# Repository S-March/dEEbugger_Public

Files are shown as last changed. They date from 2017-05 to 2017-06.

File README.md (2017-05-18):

# dEEbugger
[The dEEbugger is an ESP8266 based keychain swiss army knife for electronics](https://gfycat.com/OrneryPlushAbalone)

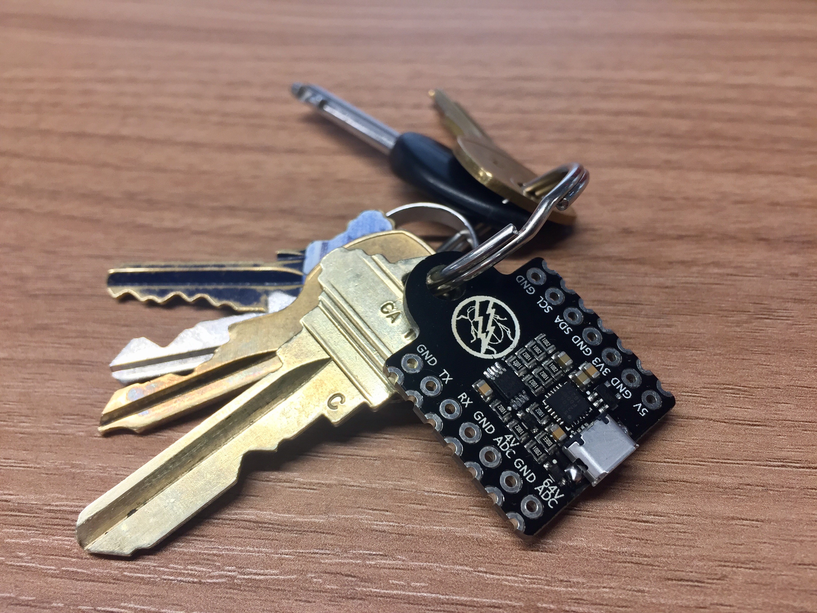
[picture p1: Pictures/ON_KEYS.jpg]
Keychain


The device was designed with breakouts for the two ADC channels, UART and I2C. It can run off of 5V or 3.3V or USB power. If USB is being used, the 5V and 3.3V pins can be used as outputs.

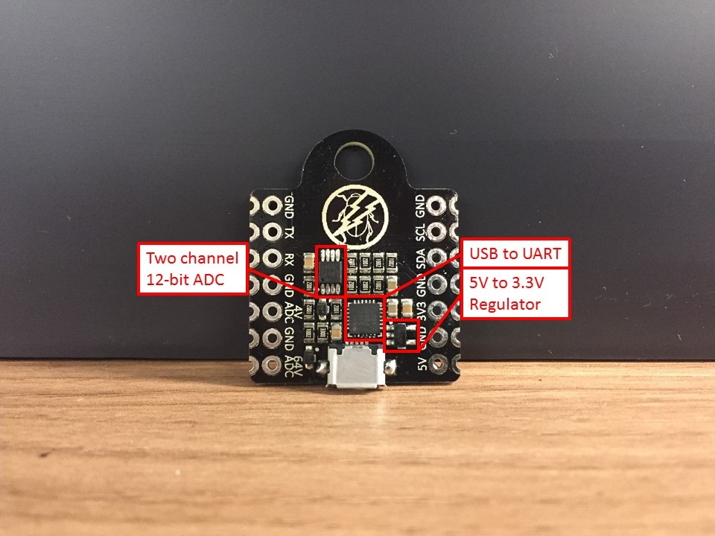
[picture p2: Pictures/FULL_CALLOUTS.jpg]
Callout Main


## Oscilloscope
To use the dEEbugger, plug in power and navigate to dEEbugger.local in you browser. If your devices does not support mDNS, you can just navigate to the dEEbugger IP address instead.

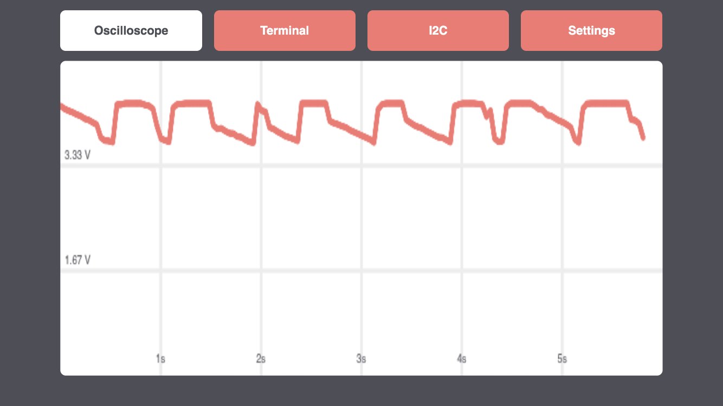
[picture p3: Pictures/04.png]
Oscilloscope Main

#### Two Channels (ADC and UART Stream)
Chose between multiple inputs for the channels. In the below picture the red is an ADC channel and the blue is a UART stream of numbers.

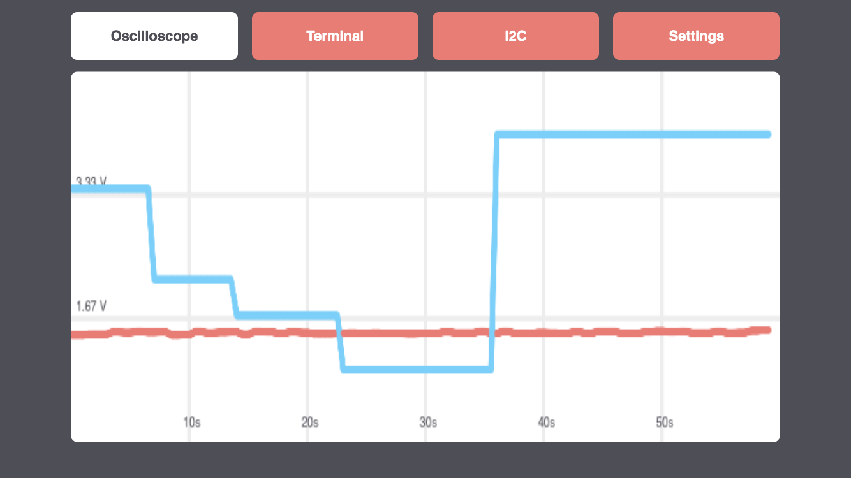
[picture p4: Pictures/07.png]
Two Channels

#### Peak Detection
The dEEbugger supports real time peak detection as well.

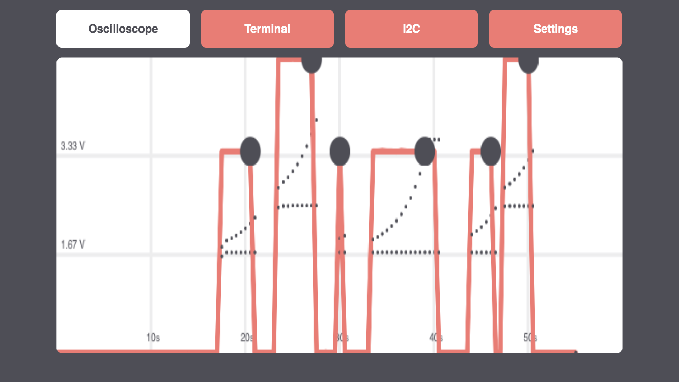
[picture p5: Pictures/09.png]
Peak Detection


## Serial Terminal
#### Local Echo
In additin to acting as an oscilloscope, the dEEbugger can act as a "wireless" serial terminal allowing you to send and receive data over the UART pins through the web application

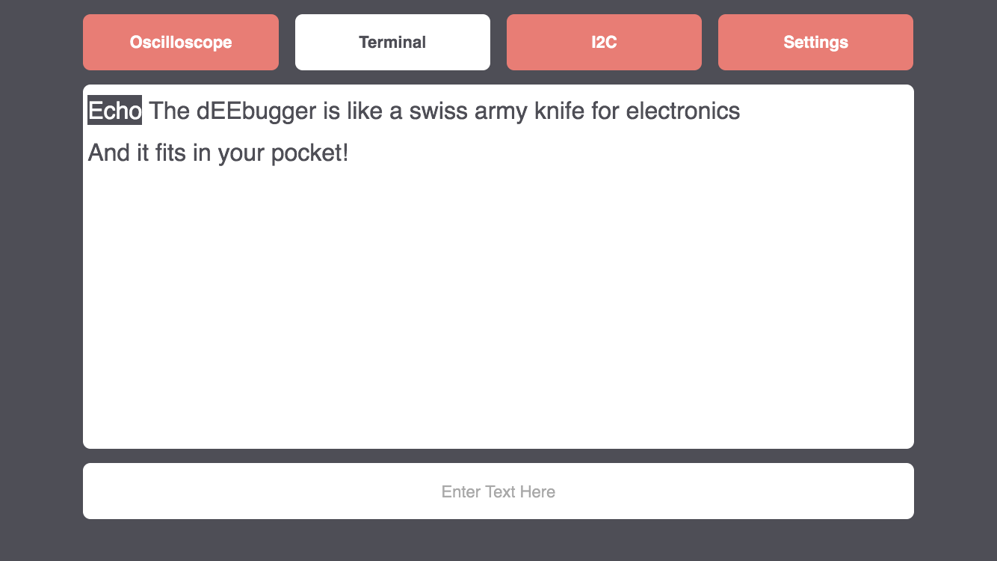
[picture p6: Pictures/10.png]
Local Echo

#### Terminal Options
Terminal settings: connect/disconnect button, baud rate selection, terminal clear button and enable/disable a local echo.

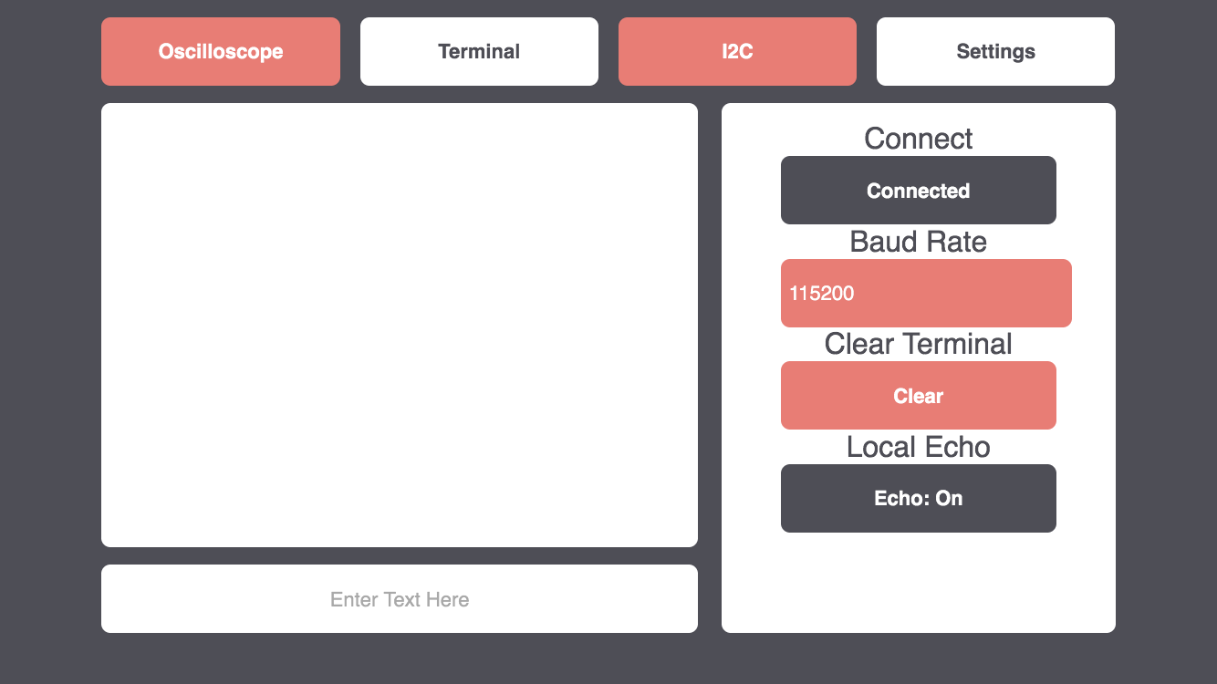
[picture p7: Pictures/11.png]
Terminal Options


## I2C Controller
#### Find Devices
When "Find Devices" button is pressed, a list of all I2C devices on the bus will be returned.

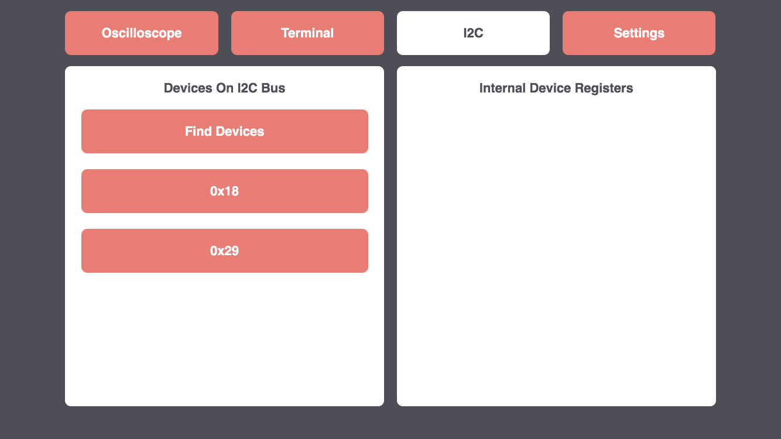
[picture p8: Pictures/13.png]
Find Devices

#### Read Device
When a device is selected, all readable registers will be returned with their current values.

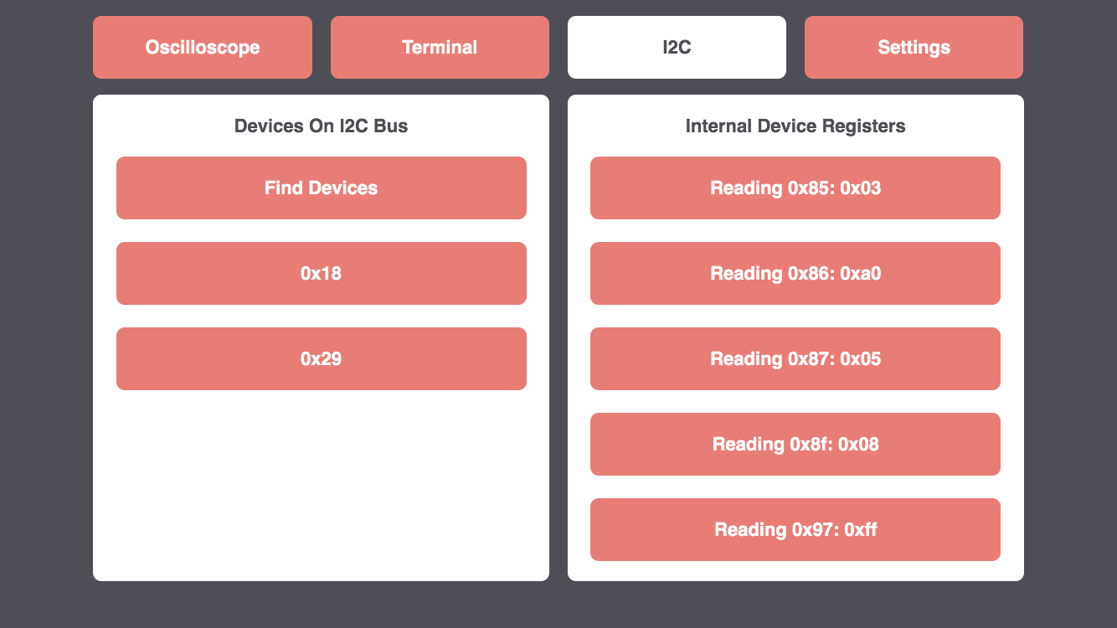
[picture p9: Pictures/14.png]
Read Device


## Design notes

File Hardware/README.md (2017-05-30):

## Fabrication
You can either send the release files to your board house of choice or you can [order PCBs directly from here](http://dirtypcbs.com/store/designer/details/Smarch/3586/deebugger-5-17-17-release-zip)
## Bill of materials
The dEEbugger_BOM file contains all the parts you will need to assemble a dEEbugger. The last column contains the distributor part number (e.g. copy and paste into Digikey) or use the link provided.
## Assembly
To assemble a dEEbugger, use the below image to place components.
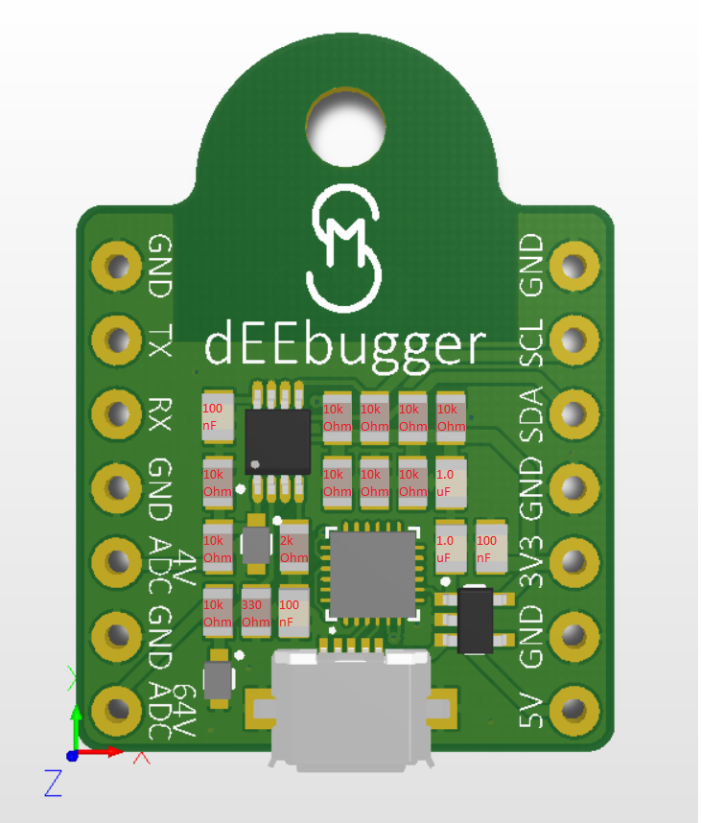
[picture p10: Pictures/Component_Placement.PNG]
Components


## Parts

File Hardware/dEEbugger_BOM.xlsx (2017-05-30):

Part Number | Quantity | Description | Comment | Supplier | Distributor | Distributor Part Number/Link
RC0805FR-0710KL | 10 | 10K 0.5W 1% 0805 | 10K | Yageo | Digikey | 311-10.0KCRCT-ND (https://www.digikey.com/products/en?keywords=311-10.0KCRCT-ND)
CL21B104MBCNNNC | 3 | CAP 100nF 10V ±20% 0805 (2012 Metric) Thickness 1mm SMD | 100nF | Samsung | Digikey | 1276-2450-1-ND (https://www.digikey.com/products/en?keywords=1276-2450-1-ND)
CL21B105KOFNNNG | 2 | CAP 1uF 10V ±20% 0805 (2012 Metric) Thickness 1.45mm SMD | 1uF | Samsung | Digikey | 1276-6471-1-ND (https://www.digikey.com/products/en?keywords=1276-6471-1-ND)
MM3Z3V3T1G | 2 | Zener Voltage Regulator, 300 mW, 2-Pin SOD-323, Pb-Free, Tape and Reel | MM3Z3V3T1G | On Semi | Digikey | MM3Z3V3T1GOSCT-ND (https://www.digikey.com/products/en?keywords=MM3Z3V3T1GOSCT-ND)
RC0805FR-072KL | 1 | 2K 0.125W 1% 0805 (2012 Metric) SMD | 2K | Yageo | Digikey | 311-2.00KCRCT-ND (https://www.digikey.com/products/en?keywords=311-2.00KCRCT-ND)
RC0805FR-07330RL | 1 | 330R 0.125W 1% 0805 (2012 Metric) SMD | 330R | Yageo | Digikey | 311-330CRCT-ND (https://www.digikey.com/products/en?keywords=311-330CRCT-ND)
AP2112K-3.3TRG1 | 1 | 3.3V LDO | AP2112K-3.3 | Diodes Inc | Digikey | AP2112K-3.3TRG1DICT-ND (https://www.digikey.com/products/en?keywords=AP2112K-3.3TRG1DICT-ND)
ESP-12F | 1 | ESP8266 Module | ESP8266 Module | Espressif | ALIEXPRESS | ALIEXPRESS (https://www.aliexpress.com/store/product/2015-New-version-1PCS-ESP-12F-ESP-12E-upgrade-ESP8266-remote-serial-Port-WIFI-wireless-module/1735233_32643052680.html)
MAX11645EUA+ | 1 | MAX11645 12 Bit Analog to Digital Converter 1, 2 Input 1 SAR 8-uMAX | MAX11645 | Maxim | Digikey | MAX11645EUA+-ND (https://www.digikey.com/products/en?keywords=MAX11645EUA%2B-ND)
CP2104-F03-GM | 1 | USB to UART bridge | USB to UART Bridge | Silicon Labs | Digikey | 336-2008-5-ND (https://www.digikey.com/products/en?keywords=336-2008-5-ND)
USB3100-30-A | 1 | Flipped USB Connector, Micro USB Type B, USB 2.0, Receptacle, 5 Positions, Surface Mount, Right Angle | USB3100-30-A Flipped USB | GCT | Newark | 07W3659 (http://www.newark.com/global-connector-technology/usb3100-30-a/micro-usb-2-0-type-b-receptacle/dp/07W3659)

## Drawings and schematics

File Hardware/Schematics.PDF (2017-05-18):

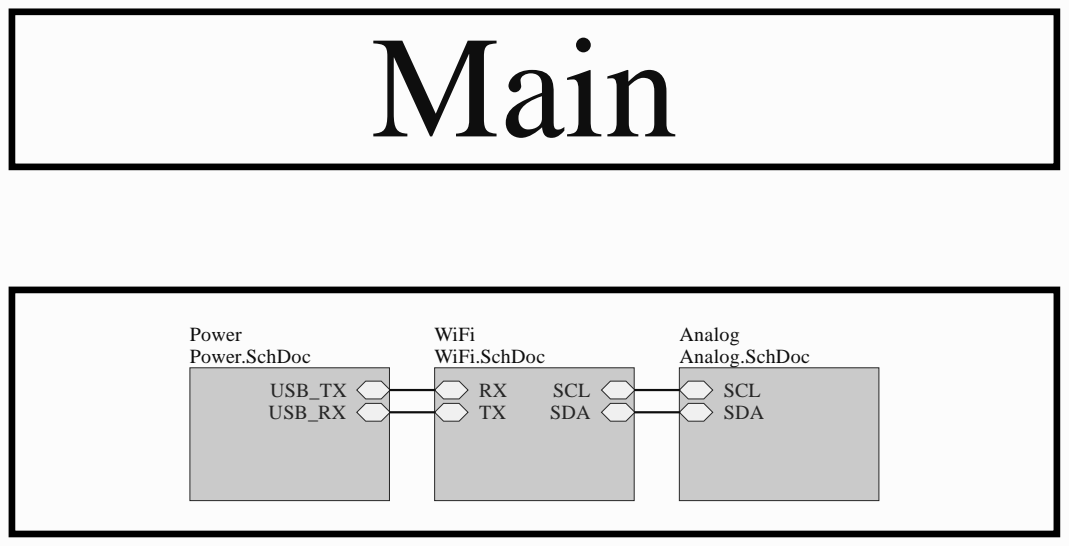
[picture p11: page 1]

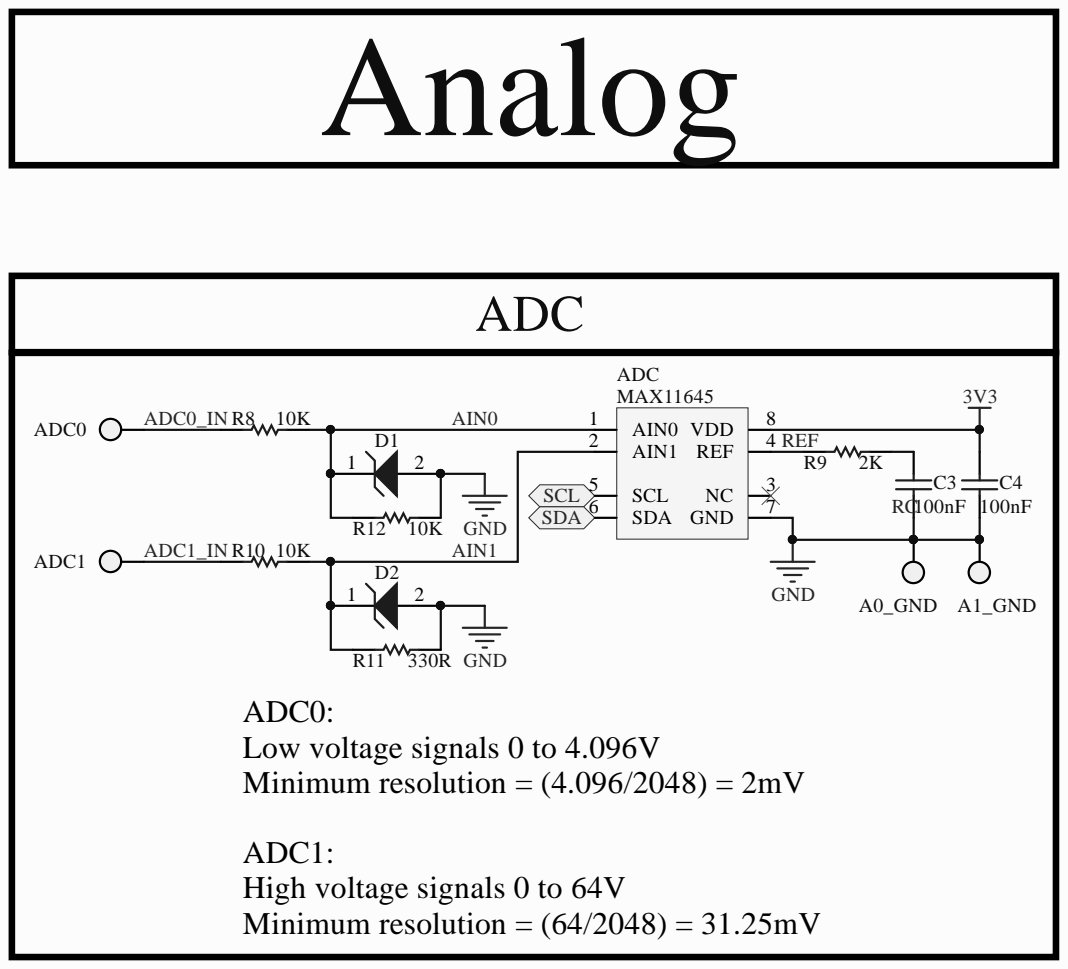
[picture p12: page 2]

ADC0:
Low voltage signals 0 to 4.096V
Minimum resolution = (4.096/2048) = 2mV

ADC1:
High voltage signals 0 to 64V
Minimum resolution = (64/2048) = 31.25mV

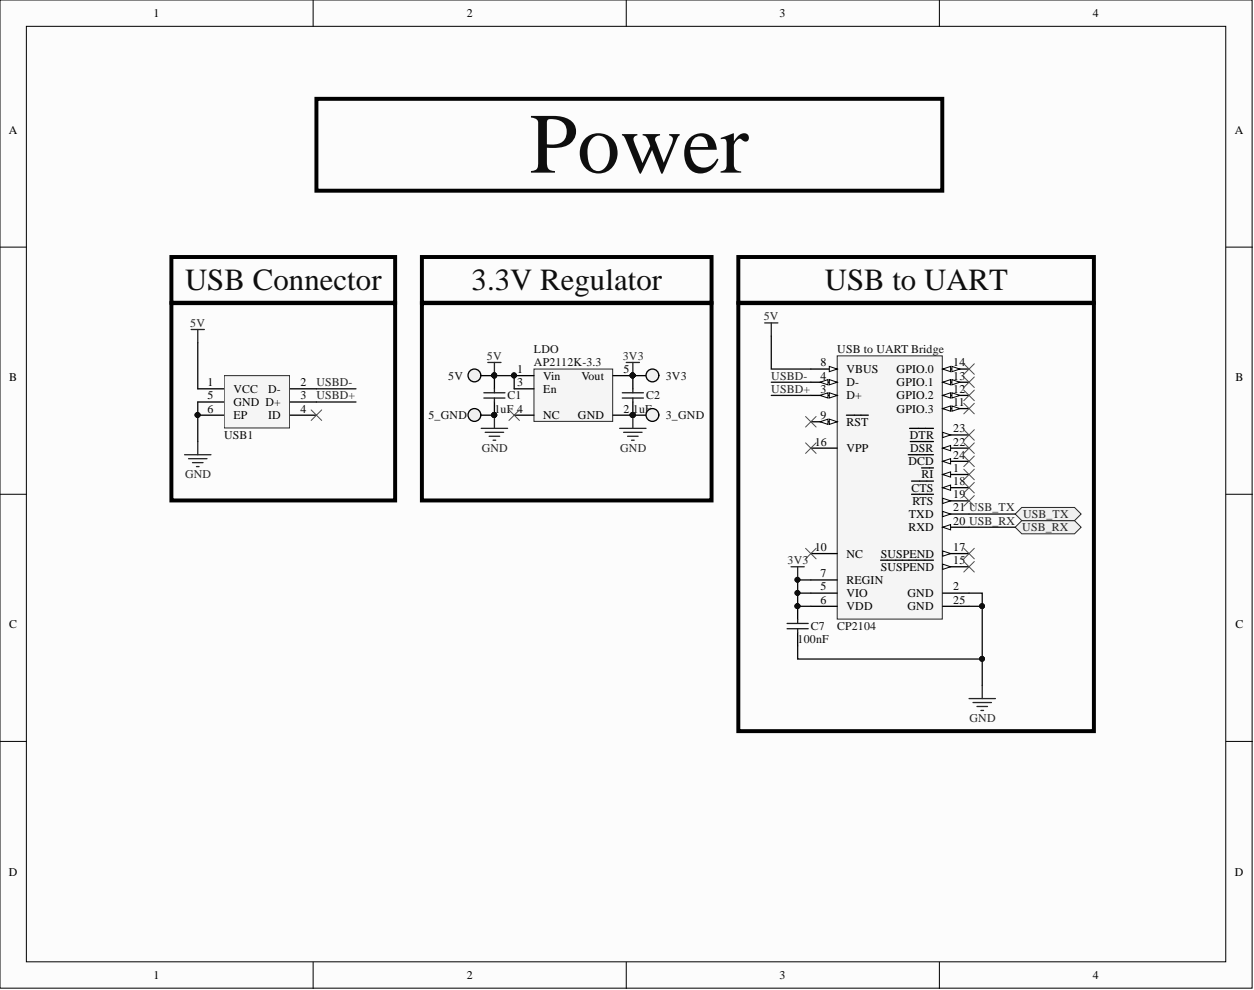
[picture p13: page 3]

USB to UART Bridge
VBUS 8

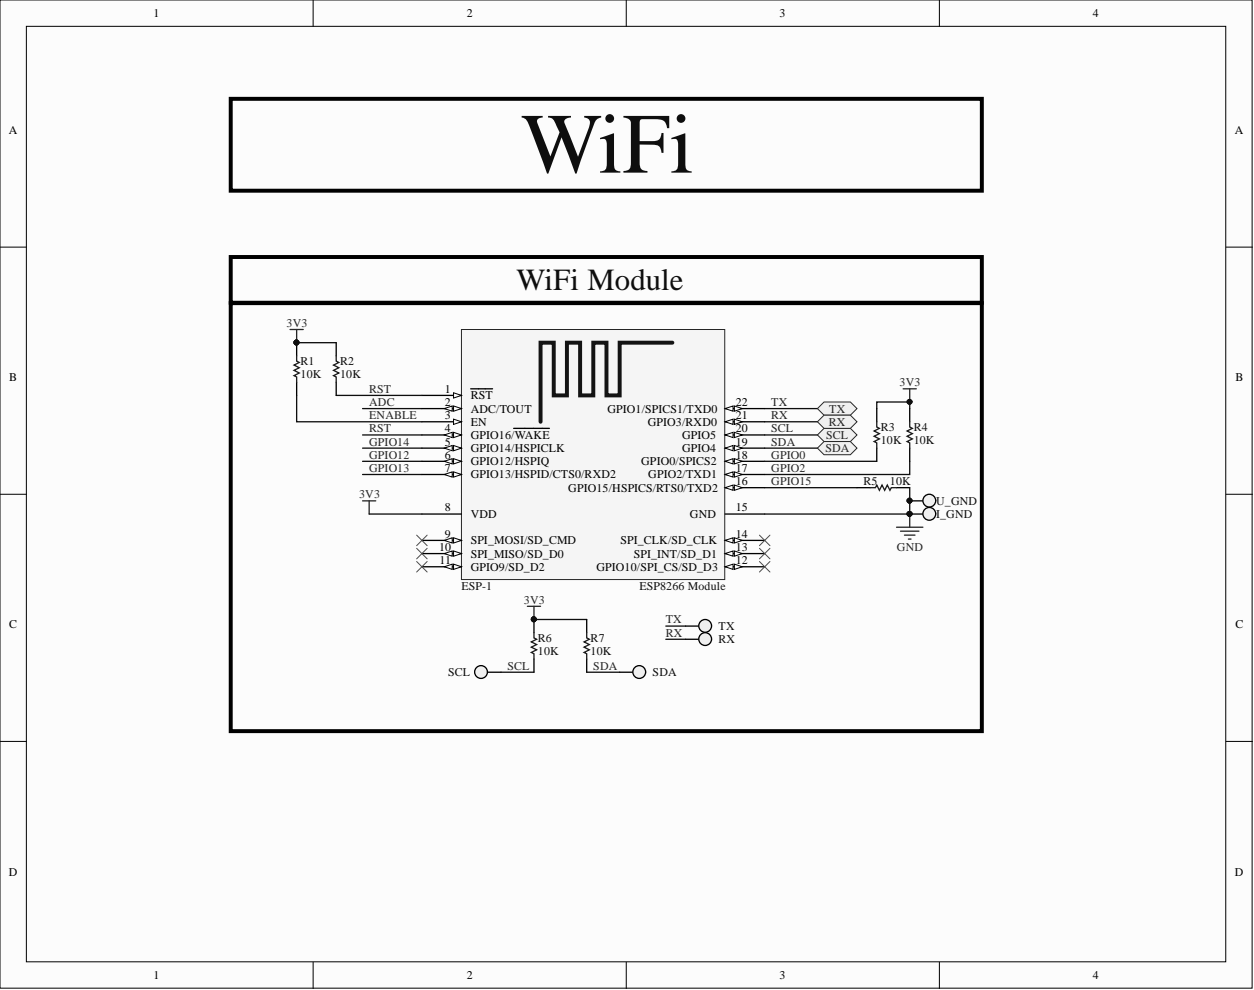
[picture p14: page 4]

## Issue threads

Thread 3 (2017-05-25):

Missing information

Tropaion, 2017-05-25:
Hello,

could you add a list of used parts and a layout diagram?
Cause It is impossible to make your project.
I dont know the foodprints you used and the type of diode.
And I dont know where to place the parts.

Thank you ;)

S-March, 2017-05-30:
Done!

Tropaion, 2017-05-30:
Thank you! ;)

Closed 2017-05-30.

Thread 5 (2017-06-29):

Graticule modifications, Int ADC reinstated, added HX711 interface

dagnall53, 2017-06-29:
Hi and thanks for an excellent piece of kit.
I have used this code as a staring point for a NODEMCU based tool for measuring force via a strain gauge and HX711 interface.
I got a bit carried away whilst exploring your code and have made some modifications to the way the graticule is presented (so it shows integer graticules) and also reinstated the "Internal ADC".
If you are interested in using my changed Graticule maths. I have placed my version in my repository as "patch 2"..
 (https://github.com/dagnall53/dEEbugger_PUBLIC/tree/patch-2)

All the best
Dagnall

dagnall53, 2017-07-10:
An apology.. I have realised that since posting I have added rather a lot of additional mods into my "patch 2" version, making it difficult for you to see just the simple graticule modifications that I thought would improve your scope display.
However, I hope that they will be helpful to you you if you decide to do any updates to your code...

S-March, 2017-08-09:
Hi Dagnall,

I just noticed all the changes you've made! I will start digging through them tonight. Looking forward to seeing what you've been up to.

dagnall53, 2017-08-09:
Hi, i have made rather a lot of mods, so it may take a bit!
First, I changed the graticule to give integer graticules. this was mainly just for my personal taste, but the modified code ended a bit complex and got me started adding other bits.

I have more recently added the ability to read HX711 strain gauge sensor. This was the main reason for my adapting the code. As part of this I have changed the way you send data to the scope handler, using a scaling factor for each channel. I am sure you can see how this works. The HX711 can read 25 samples/second when in single channel mode, but changeover of channels takes about 250+ms, so this really limits how the two channel strain sensor can work. My current code defaults to 500ms single channel sample rate. Hoping to improve the sample rate I gave interleaved the two channel reads,  With slow sample rates this then showed up badly on the screen, so I modified the screen display to try and time interleave the channel displays. In doing this I think I noticed a few left over variables you may have been using to try and do the same thing.. Currently, after settling down, the display updates each line as it receives the data.  To make this display properly, I detect which channel is read first after a clear screen, and shift the display of the "second" channel half a sample period.. With faster sample rates this interleaving would not be necessary as you would not notice the slight shift.

Today I also added an On screen Display to show the channel readings. I have not tested this with faster sample rates and it may need to have some feature to only show one every n samples (or average of n samples) at a slower update rate for when the ADC is at high data rates?

For the strain gauge display there is an ugly (but functional) modification to the vertical axis to shift the display up one unit, and to change the display from V to kg.

If you want to try out the HX711, please make sure you use my modified HX711 library, as it works with the ESP!.   The owner of the real library has not yet added my mod!.

I would be happy to explain any other changes.. Most are identified with "DAG", although in future I may just leave the Git compare function to show the changes...

Let me know if there are any explanations I can help with.. And thanks for some very impressive software
Dagnall

dagnall53, 2017-08-09:
closed in error, now re-opened...

dagnall53, 2017-08-09:
One last thing.. I modified the default behaviour for selecting AP or "log in" mode on wake up.. I could not see exactly what you were doing, and wanted the deebugger to normally log into my network. I also use the WiFi Manager routine which loads an AP to ask for network address/ password if it cannot log in. I suspect that this may screw up your original intent to load in an AP mode when out and about.. I tried to sort out a pin to select modes on startup like I think you do, but have not progressed this.

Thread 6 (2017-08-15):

ADC sample rate and scopeHandler rate?

dagnall53, 2017-08-15:
@S-March
Hi, I have been looking in more detail at the code and was wondering if you can help explain some details about the timings...
I think that in your original code the "esp" is reading the ADC every 5ms, and then calling the "scopeHandler" code at "mstimer" intervals to update the display, using the most recent adc readings. thus sending ADC data to the display PC/tablet.
BUT, I have been looking at the timings, and the scopehandler code seems to take about 200ms to complete, and only sends one sample from each channel?
I suspect I have "broken" something critical so that any "fast" ADC (eg internal) is now being hobbled by this slow scopeHandler code, quite probably by some edits I have made.
What update rate can you achieve with the original code? I did try to reinstall an early version,but still got 200ms or thereabouts timings for the scopeHandler code part.

   Any suggestions, comments or hints gratefully accepted!
Cheers
Dagnall

(I have currently updated the code (again) so that the HTML stuff sorts out a sensible "mSTimer" based on which  and how many ADC's it is using and sends this to the ESP .. But I will not upload this until I think the speed issue is sorted.)

S-March, 2017-08-15:
Hi Dagnall

I'll have to look at the code again after work.

But as I recall the 200ms rate was set intentionally due to the amount of data being streamed. The JS couldn't handle plotting faster than 5ms intervals. But needed around 200ms to do it.

So my work around was to store 8 ADC samples in a buffer and then send the 8 sample buffer over web sockets once every 200ms. That way the webpage could plot 8 data points while waiting for the next set.

Let me know if this helps.

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

dagnall53, 2017-08-15:
@S-March  thanks, that makes sense, I must have upset or removed the mechanism that stores the readings in a buffer.. I can now see the addadcscopedata functions are called or should be called a few times before the scope handler is called... I think my mods have not take that into account!
I will try to set some interactions so that the code works both with fast adc and the really slow two channel strain gauge interface.

Thanks
D

S-March, 2017-08-15:
No prob, good luck!

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

dagnall53, 2017-08-16:
@S-March
Quick update, it was mostly my fault, when I modified the way the scaling was applied, I  ended up converting the multiple readings to a single one... Dohh..
I've nearly corrected it. I've also set a long period between html updates, 1.5 sec, so can now get a lot of adc readings in that time. Of course, the adc readings from sequential websends are out of time synch, so I'm working on some details around this to essentially try to display only a 'full set' of data at a time. But have a few issues in that the adc readings are stopped whilst the web server is updated.

In doing this i have also moved the data logging send to the adc routine, from the web update routine where it was it only sent (one) data when sending to the  HTML . Not sure if I introduced this or it was there before..

I have one last and very irritating issue: the scope plot (in my version) does not completely plot to the right hand edge of the plot area. If the set of data points being plotted exceeds the plot area, the clear plot is immediately called before the last plot lines are written... This is not so troublesome with time scales of 10 sec or longer, but with expansion and especially on the 2s scale, there can be more plot points than space and so clear plot happens immediately and there is no visible plot. Quite difficult to explain, not sure if this is another bug I introduced or one that was there before... Anyway, I think I need to synchronise the clear with new data arriving. Or  I may try to reduce the number of data points so they fit, but would prefer an alternative solution...
Anyway, cheers!
Dagnall

dagnall53, 2017-08-17:
@S-March
OK, I have got it working (again).. !
New code and some pictures are at
https://github.com/dagnall53/dEEbugger_PUBLIC/blob/patch-2/README.md
I have set the defaults to "single channel , internal ADC", so is should work "out of the box" with a Node MCU.

Hope you like it. I do not have the same I2C ADC as you so have not been able to test that feature, but hopefully it should be still working.
The HX711 strain gauge interface and internal ADC stuff have now been tested to my satisfaction, and I have added tweaks so the scope display shows blanks where no ADC reading have been taken.

The code is still littered with comments and commented out lines where I changed my mind or was working on something or trying to see what happened, but hopefully they will assist if you are trying to see what I did.
Cheers
Dagnall

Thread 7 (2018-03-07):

Soldering temperature for CP2104

infrat, 2018-03-07:
Hi. I've ordered few PCBs of dEEbugger on JLCPCB, completed parts and for now, I started to solder everything together.

Unfortunately after mounting USB connector, LDO and CP2102, I can't see any new USB-Serial converters devices list in my computer (in my case I've decided to use QFN24 version of CP2102 instead, because of better availability in my country; it seems they are fully compatible with CP2014).

So it seems I've baked CP2102 using my hot-air station. And my question is how you soldered CP2104 in your case? Have you used soldering iron, or hot-air station? If you've used hot-air, what was your temperature settings?

infrat, 2018-03-12:
I'm closing issue, because I've found out I've been testing CP210x without few capacitors which are required to boot up CP210x. Now it works like a charm.

Closed 2018-03-12.

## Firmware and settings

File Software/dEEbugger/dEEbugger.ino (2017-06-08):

#include <Arduino.h>
#include <ESP8266WiFi.h>
#include <ESP8266WiFiMulti.h>
#include <WebSocketsServer.h>
#include <Hash.h>
#include <ESP8266WebServer.h>
#include <ESP8266mDNS.h>
#include <WiFiClient.h>
#include <WiFiUdp.h>
#include <ArduinoOTA.h>
#include <DNSServer.h>
#include <WiFiManager.h>
#include <Wire.h>
#include "miniDB.h"
#include "websiteHTML.h"
#include "WebsocketInterpreter.h"

#define APMODE_BOOT_PIN 4

void webSocketEvent(uint8_t num, WStype_t type, uint8_t * payload, size_t length);
void handleRoot();
void handleNotFound();
void serialEvent();

boolean bootAPFlag = true;

String inputString = "";
int uartIntData = -1;
boolean stringComplete = false;
String webSocketData = "";

unsigned long oldTime = 0;
unsigned long oldTimeADC = 0;
unsigned long currentTime = 0;

const char *ssid = "dEEbugger";
const char *password = "DEBUGGIN4DAYZ";

MDNSResponder mdns;

ESP8266WiFiMulti WiFiMulti;

ESP8266WebServer server(80);
WebSocketsServer webSocket = WebSocketsServer(81);

void setup()
{  
  Serial.begin(115200);
  if(digitalRead(APMODE_BOOT_PIN))
  {
    WiFi.disconnect();
    WiFi.softAP(ssid, password);
    Serial.println();
    Serial.println("Booting in AP mode");
    Serial.println("Go to 192.168.4.1 to access the dEEbugger");
    Serial.println("NOTE: OTA is NOT available in AP mode");
  }
  else
  {
    Serial.println();
    Serial.println("Booting in client mode");
    Serial.println("OTA is available");
    WiFiManager wifiManager;
    wifiManager.autoConnect(ssid,password);
    Serial.println();
    Serial.print("IP address: ");  
    if (!MDNS.begin("dEEbugger"))
    {
      Serial.println("Error setting up MDNS responder!");
      while(1)
      { 
        delay(1000);
      }
    }
    Serial.println("mDNS responder started");
  
    Serial.print("Connect to http://dEEbugger.local or http://");
    Serial.println(WiFi.localIP());
    
    MDNS.addService("http", "tcp", 80);
    MDNS.addService("ws", "tcp", 81); 
  }

  ArduinoOTA.setHostname("dEEbugger");
  ArduinoOTA.onStart([]()
  {Serial.println("Start");});
  ArduinoOTA.onEnd([]()
  {Serial.println("\nEnd");});
  ArduinoOTA.onProgress([](unsigned int progress, unsigned int total)
  {Serial.printf("Progress: %u%%\r", (progress / (total / 100)));});
  ArduinoOTA.onError([](ota_error_t error)
  {
    Serial.printf("Error[%u]: ", error);
    if (error == OTA_AUTH_ERROR) Serial.println("Auth Failed");
    else if (error == OTA_BEGIN_ERROR) Serial.println("Begin Failed");
    else if (error == OTA_CONNECT_ERROR) Serial.println("Connect Failed");
    else if (error == OTA_RECEIVE_ERROR) Serial.println("Receive Failed");
    else if (error == OTA_END_ERROR) Serial.println("End Failed");
  });
  ArduinoOTA.begin();

  server.on("/", handleRoot);
  server.onNotFound(handleNotFound);
  server.begin();

  webSocket.begin();
  webSocket.onEvent(webSocketEvent);
  
  Wire.begin(); 

  scopeInit();
  setMsTimer(40);
}

void loop()
{  
  currentTime = millis();
  serialEvent();
  ArduinoOTA.handle();
  webSocket.loop();
  server.handleClient();
  if((currentTime - oldTimeADC)>=5)
  {
    ADCHandler();
    oldTimeADC = currentTime;
  }
  if(webSocketData!="")
  {
    webSocketDataInterpreter(webSocket, webSocketData);
    webSocketData = "";
  }
  if((currentTime - oldTime)>=getMsTimer())
  {
    scopeHandler(webSocket);
    webSocketData = "";
    oldTime = currentTime;
  }
}

void webSocketEvent(uint8_t num, WStype_t type, uint8_t * payload, size_t length)
{
  switch(type)
    {
    case WStype_DISCONNECTED:
        Serial.printf("[%u] Disconnected!\r\n", num);
        break;
    case WStype_CONNECTED:
        {
        IPAddress ip = webSocket.remoteIP(num);
        Serial.printf("[%u] Connected from %d.%d.%d.%d url: %s\r\n", num, ip[0], ip[1], ip[2], ip[3], payload);
        }
        break;
    case WStype_TEXT:
         webSocketData = String((const char *)payload);
        break;
    case WStype_BIN:
        Serial.printf("[%u] get binary length: %u\r\n", num, length);
        hexdump(payload, length);

        // echo data back to browser
        webSocket.sendBIN(num, payload, length);
        break;
    default:
        Serial.printf("Invalid WStype [%d]\r\n", type);
        break;
    }
}

void handleRoot()
{
  server.send_P(200, "text/html", INDEX_HTML);
}

void handleNotFound()
{
  String message = "File Not Found\n\n";
  message += "URI: ";
  message += server.uri();
  message += "\nMethod: ";
  message += (server.method() == HTTP_GET)?"GET":"POST";
  message += "\nArguments: ";
  message += server.args();
  message += "\n";
  for (uint8_t i=0; i<server.args(); i++){
    message += " " + server.argName(i) + ": " + server.arg(i) + "\n";
  }
  server.send(404, "text/plain", message);
}

void serialEvent()
{
  while (Serial.available())
  {
    char inChar = (char)Serial.read();
    if (inChar == '\n') {
      stringComplete = true;
      return;
    } else {
      inputString += inChar;
    }
  }
  if (stringComplete) {
    if(getUartScopeFlag())
    {
      uartIntData = inputString.toInt();
      if(uartIntData)
      {
        setUartScopeData(inputString);
        Serial.println(inputString);
      }
      else if(inputString == "0")
      {
        setUartScopeData(inputString);
        Serial.println(inputString);
      }
      else
      {
        String line = "SERIAL UART " + inputString;
        webSocket.broadcastTXT(line);
        Serial.println(line);
      }
    }
    else{
      String line = "SERIAL UART " + inputString;
      webSocket.broadcastTXT(line);
      Serial.println(line);
    }
    inputString = "";
    stringComplete = false;
  }
}

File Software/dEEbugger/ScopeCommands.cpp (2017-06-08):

#include "ScopeCommands.h"

String channelModeOutput1;
String channelModeOutput2;
bool toggledChannelOffFlag1;
bool toggledChannelOffFlag2;
byte ADCAddress = 54;

void scopeInit(void)
{
  setChannelMode1("OFF");
  setChannelMode1("OFF");
  toggledChannelOffFlag1 = false;
  toggledChannelOffFlag2 = false;
  channelModeOutput1 = "";
  channelModeOutput2 = "";
  setUartScopeData("0");
  ADCInit();
}
void scopeHandler(WebSocketsServer &WEBSOCKETOBJECT)
{
  //Channel 1
  if((getChanneMode1()=="4V ADC")||(getChanneMode1()=="64V ADC"))
  {
    toggledChannelOffFlag1 = false;
    channelModeOutput1 = "SCOPE ADC DATACHANNEL1";
    channelModeOutput1 += getADCScopeData1();    
    WEBSOCKETOBJECT.broadcastTXT(channelModeOutput1);
    if(getDataLog())
    {
      Serial.print("CHANNEL1, ");
      Serial.println(getADCScopeData1());
    }
    clearADCScopeData1();
  }
  if(getChanneMode1()=="UART")
  {
    toggledChannelOffFlag1 = false;
    channelModeOutput1 = "SCOPE UART DATACHANNEL1";
    channelModeOutput1 += getUartScopeData();
    WEBSOCKETOBJECT.broadcastTXT(channelModeOutput1);
    clearUartScopeData();
  }
  if(getChanneMode1()=="OFF")
  {
    if(!toggledChannelOffFlag1)
    {
      toggledChannelOffFlag1 = true;
      channelModeOutput1 = "SCOPE OFF DATACHANNEL1";
      channelModeOutput1 += " 0";
      WEBSOCKETOBJECT.broadcastTXT(channelModeOutput1);
    }
  }
  //Channel 2
  if((getChanneMode2()=="4V ADC")||(getChanneMode2()=="64V ADC"))
  {
    toggledChannelOffFlag2 = false;
    channelModeOutput2 = "SCOPE ADC DATACHANNEL2";
    channelModeOutput2 += getADCScopeData2();    
    WEBSOCKETOBJECT.broadcastTXT(channelModeOutput2);
    if(getDataLog())
    {
      Serial.print("CHANNEL2, ");
      Serial.println(getADCScopeData2());
    }
    clearADCScopeData2();
  }
  if(getChanneMode2()=="UART")
  {
    toggledChannelOffFlag2 = false;
    channelModeOutput2 = "SCOPE UART DATACHANNEL2";
    channelModeOutput2 += getUartScopeData();
    WEBSOCKETOBJECT.broadcastTXT(channelModeOutput2);
    clearUartScopeData();
  }
  if(getChanneMode2()=="OFF")
  {
    if(!toggledChannelOffFlag2)
    {
      toggledChannelOffFlag2 = true;
      channelModeOutput2 = "SCOPE OFF DATACHANNEL2";
      channelModeOutput2 += " 0";
      WEBSOCKETOBJECT.broadcastTXT(channelModeOutput2);
    }
  }
}
void ADCInit(void)
{
  	byte internalError;
    byte ADCSetupByte = 210;
	byte ADCConfigByte = 97;
    Wire.beginTransmission(ADCAddress);
    Wire.write(ADCSetupByte);
    Wire.write(ADCConfigByte);
    internalError = Wire.endTransmission();
	if (internalError == 0)
	{
		Serial.println("ADC Initialized");
	}
}
void setADCChannel(int CHANNEL)
{   
    byte internalError, ADCConfigByte;
    //Select correct channel
    switch(CHANNEL)
    {
        case 0:
            ADCConfigByte = 97;
            break;
        case 1:
            ADCConfigByte = 99;
            break;
        default:
            ADCConfigByte = 97;
            break;
    }
    //Send channel selection
    Wire.beginTransmission(ADCAddress);
    Wire.write(ADCConfigByte);
    internalError = Wire.endTransmission();
    if (internalError != 0)
    {
        Serial.println("Error setting ADC channel");
    }
}
int ADCRead(void)
{
	//Read channel
	Wire.requestFrom(ADCAddress, 2); 
    if (Wire.available() > 0)
    { 
        byte ADCResultMSB = Wire.read();
        byte ADCResultLSB = Wire.read();
        uint16_t ADCResult = (((ADCResultMSB<<8)|ADCResultLSB)&0x0FFF);
        return ADCResult;
	}
}
void ADCHandler(void)
{
    if(getChanneMode1()=="4V ADC")
    {
        setADCChannel(0);
        addADCScopeData1(String(ADCRead()));
    }
    if(getChanneMode1()=="64V ADC")
    {
        setADCChannel(1);
        addADCScopeData1(String(ADCRead()));
    }
    if(getChanneMode2()=="4V ADC")
    {
        setADCChannel(0);
        addADCScopeData2(String(ADCRead()));
    }
    if(getChanneMode2()=="64V ADC")
    {
        setADCChannel(1);
        addADCScopeData2(String(ADCRead()));
    }
}

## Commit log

2017-05-18 Added release files
    [dEEbugger_V5.GBL, dEEbugger_V5.GBO, dEEbugger_V5.GBP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]
2017-05-18 Added schematics and update to readme
2017-05-30 Added BOM and placement info
    Added the bill of materials as well as an image to show placement on the
    board.
    [dEEbugger_BOM.xlsx]
2017-05-30 Fixed link in assembly page
2017-05-30 Added link to PCB fab page
2017-06-08 Updates to handle I2C ADC
    Main:
    - Moved ADC conversions to ADCHandler();
    I2CCommands:
    - Removed I2C device 54 (ADC) from being part of scan to prevent messing
    up configuration settings
    MiniDB:
    - Split ADC data into two channels (set/get/clear functions)
    ScopeCommands:
    - Added ADCHandler(); which looks at the ADC mode for each channel and
    changes the I2C ADC channel accordingly
    HTML:
    - Made channel 1 default to 4V and channel 2 default to 64V.
    - Made y axis divisions multiples of 4 rather than 3
    - Added check in plot function to see if incoming value needs to be
    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
    [I2CCommands.cpp, ScopeCommands.cpp, dEEbugger.ino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]
